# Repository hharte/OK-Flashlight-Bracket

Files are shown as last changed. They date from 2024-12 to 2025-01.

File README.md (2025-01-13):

# Speed-Wrap Flashlight Bracket

# Introduction

The OK Industries Speed-Wrap wire wrapping tool is useful for telecom and electronics work, where wire-wrapped connections are needed.

Over the years, the Speed-Wrap has been available in several models, most of which are still available today.

This project is a small 3D-printable bracket designed with [FreeCAD](https://freecad.org), that mounts to the rear of the tool, providing a stable mounting for a small flash light such as the [ThruNite Archer Mini](https://www.amazon.com/dp/B09XDTX7MX) or [Archer Pro v2](https://www.amazon.com/ThruNite-Flashlight-Archer-Pro-Rechargeable/dp/B0C2XSKKCT).

# Speed-Wrap Models

<table>
  <tr>
   <td>Model
   </td>
   <td>Bell System KS Number
   </td>
   <td>Description
   </td>
  </tr>
  <tr>
   <td>G-100
   </td>
   <td>KS-16363L1
   </td>
   <td>Aluminum housing
   </td>
  </tr>
  <tr>
   <td>G-100/R3278
   </td>
   <td>KS-16363L2
   </td>
   <td>Aluminum housing, newer style nose piece 
   </td>
  </tr>
  <tr>
   <td>G-200/R3278
   </td>
   <td>KS-16363L3
   </td>
   <td>Lexan housing, newer style nose piece 
   </td>
  </tr>
</table>

# Flashlights Supported

<table>
  <tr>
   <td>Brand
   </td>
   <td>Model
   </td>
   <td>Description
   </td>
  </tr>
  <tr>
   <td><a href="https://www.amazon.com/stores/ThruNite/page/18B3D79C-AD8C-49E3-A9F4-4489BCBD6C78">ThruNite</a>
   </td>
   <td><a href="https://www.amazon.com/dp/B09XDTX7MX">Archer Mini</a>
   </td>
   <td>14mm diameter body, USB-C charging.
   </td>
  </tr>
  <tr>
   <td><a href="https://www.amazon.com/stores/ThruNite/page/18B3D79C-AD8C-49E3-A9F4-4489BCBD6C78">ThruNite</a>
   </td>
   <td><a href="https://www.amazon.com/ThruNite-Flashlight-Archer-Pro-Rechargeable/dp/B0C2XSKKCT">Archer Pro v2</a>
   </td>
   <td>18mm diameter body, USB-C charging.
   </td>
  </tr>
</table>

# Installation

Use the included STL mesh files (14mm or 18mm) to print the bracket using a 3D printer.  I suggest using PETG filament for strength.  Use an M3x20 cap head bolt and M3 nut to attach the bracket to the rear of the Speed-Wrap.

Use two small zip ties to secure the flashlight to the top of the bracket.

# Photos

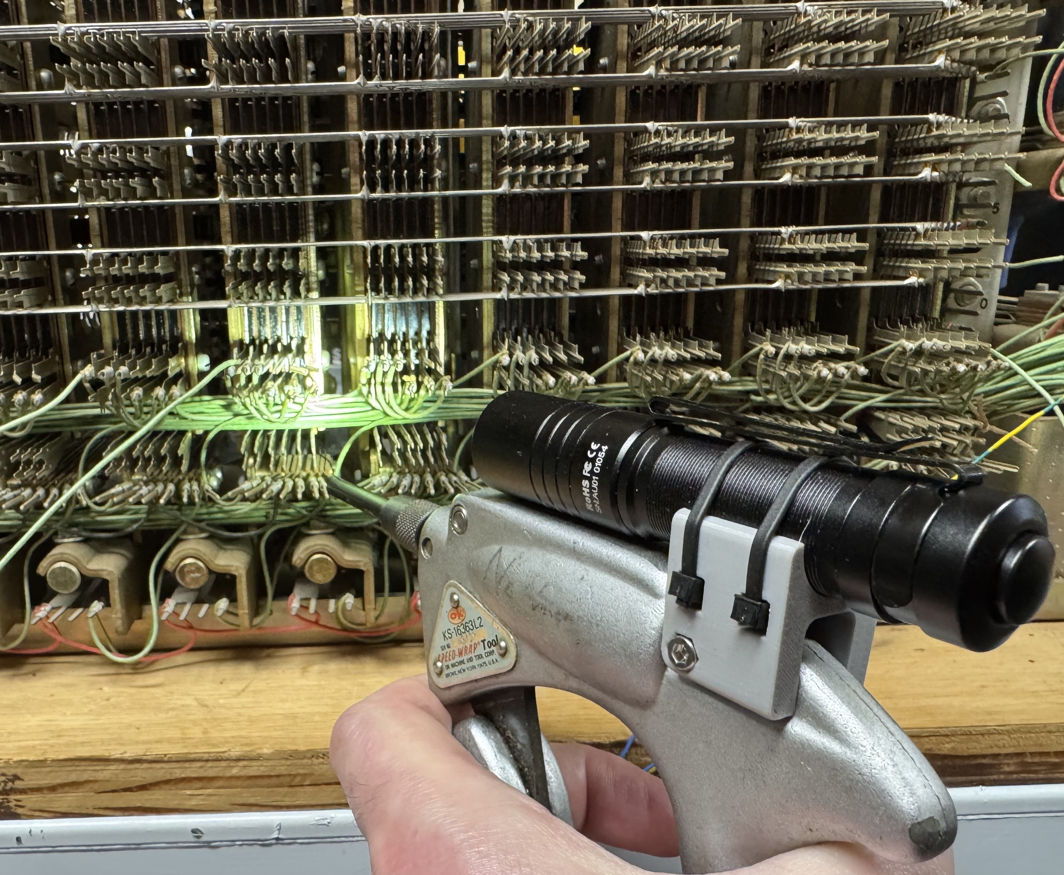
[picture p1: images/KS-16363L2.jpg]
Photo of the assembled bracket and Archer Pro v2 flashlight on a KS-16363L2 Speed-Wrap tool. image_tooltip


## Assembled bracket and Archer Pro v2 flashlight on a KS-16363L2 Speed-Wrap tool.

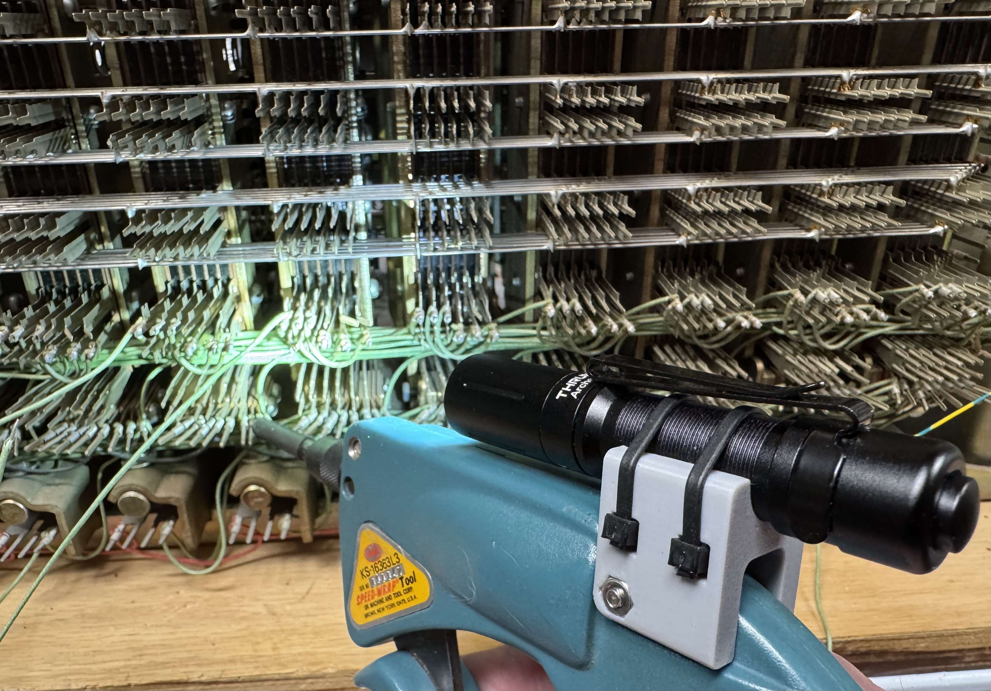
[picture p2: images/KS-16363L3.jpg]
Photo of the assembled bracket and Archer Mini flashlight on a KS-16363L3 Speed-Wrap tool. image_tooltip


## Assembled bracket and Archer Mini flashlight on a KS-16363L3 Speed-Wrap tool.

# Cleaning, Lubricating, Rebuilding

Remove all old grease from the gears, and if the bearings don’t spin freely, you may need to remove the old grease from those as well, and re-pack.  You can 3D-print the `BearingGreaseFitting.stl` to help re-pack the bearings, or you can simply replace the bearings.

The bearings are ⅜” OD, ⅛” ID, 5/32” Width.  These are some of the available bearing replacements on Amazon:

[https://www.amazon.com/HiPicco-R2-2RS-Bearings-Bearing-Pre-Lubricated/dp/B0C74WTY1K](https://www.amazon.com/HiPicco-R2-2RS-Bearings-Bearing-Pre-Lubricated/dp/B0C74WTY1K)

[https://www.amazon.com/uxcell-R2-2RS-Groove-Bearing-Bearings/dp/B0824WN2RB](https://www.amazon.com/uxcell-R2-2RS-Groove-Bearing-Bearings/dp/B0824WN2RB)

[https://www.amazon.com/uxcell-8-inchx3-8-inchx5-Shielded-Bearings/dp/B0824VSF74](https://www.amazon.com/uxcell-8-inchx3-8-inchx5-Shielded-Bearings/dp/B0824VSF74)

***<span style="text-decoration:underline;">Note:</span>***

When cleaning and lubricating the gears and bearings, it is very important to get the ring gear aligned properly.  Don’t press the bearing all the way into the recess in the case.  Instead, press the bearing in slightly, just enough to hold the ring gear in place while you assemble the tool.  While tightening the case, the bearing will be pushed into the recess just enough to maintain proper contact with the pinion gear.  If the tool is noisy, or doesn’t return quickly when the handle is released, the gear alignment is most likely incorrect.  Take it apart again, and assemble as described above.

## Lubrication of gears

Use a small amount of a light grease such as [Permatex White Lithium Grease](https://www.amazon.com/dp/B000HBNV58).

# References

[Manual Wire Wrapping Tools User’s Guide](https://jonard.com/sites/default/files/product_files/Manual%20Wire%20Wrapping%20Tools%20Users%20Guide%20%284%29.pdf)

[Jonard Wire Wrap Tool Page](https://jonard.com/manual-wire-wrap-and-unwrap-guns-0)

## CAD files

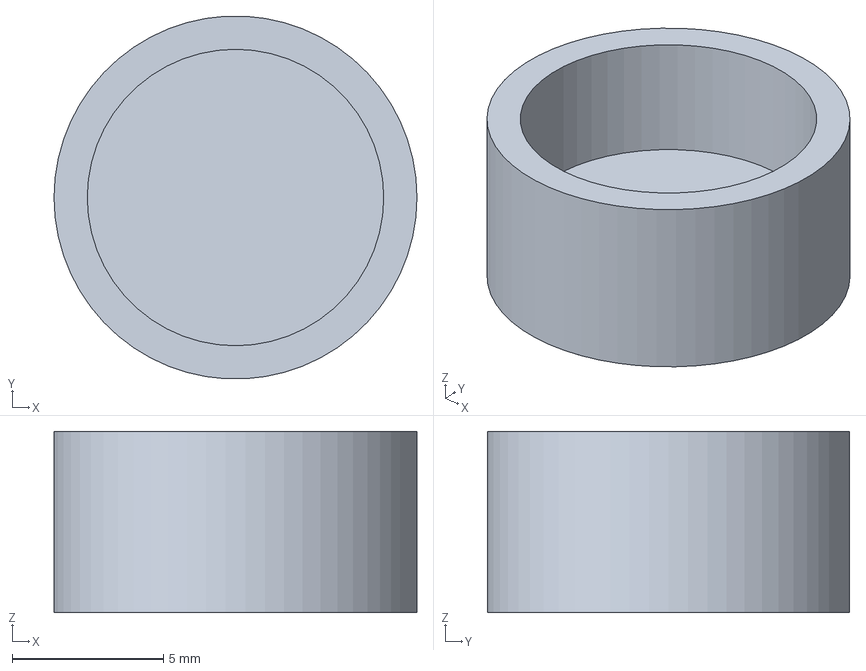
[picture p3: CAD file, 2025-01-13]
BearingGreaseFitting.FCStd
12.0 x 12.0 x 6.00 mm

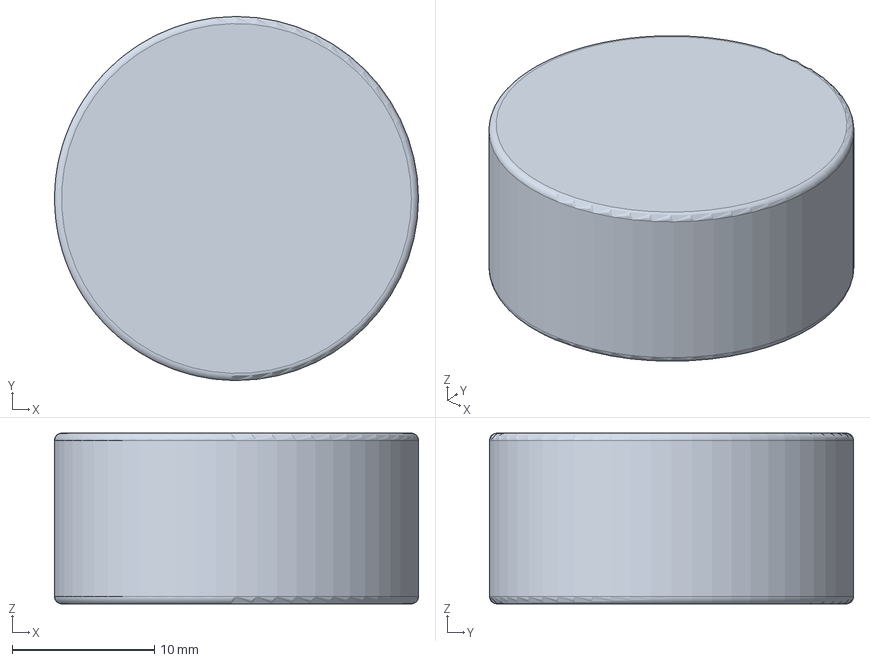
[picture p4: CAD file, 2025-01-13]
BatteryCap.FCStd
25.6 x 25.6 x 12.0 mm

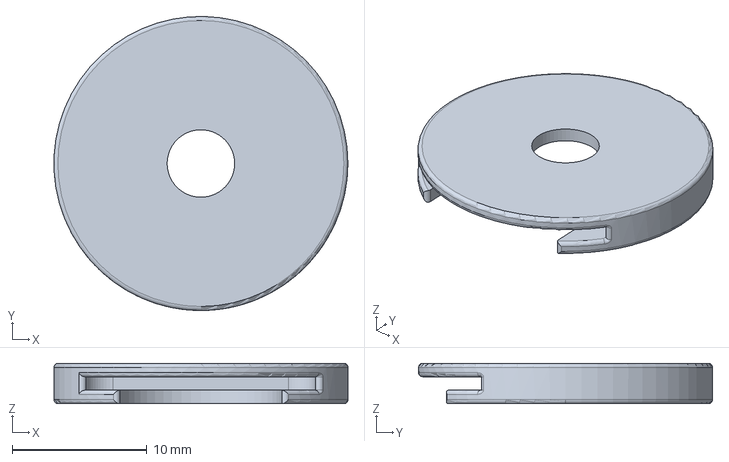
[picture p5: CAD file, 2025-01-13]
BatterySpringBase.FCStd
21.8 x 21.8 x 3.00 mm

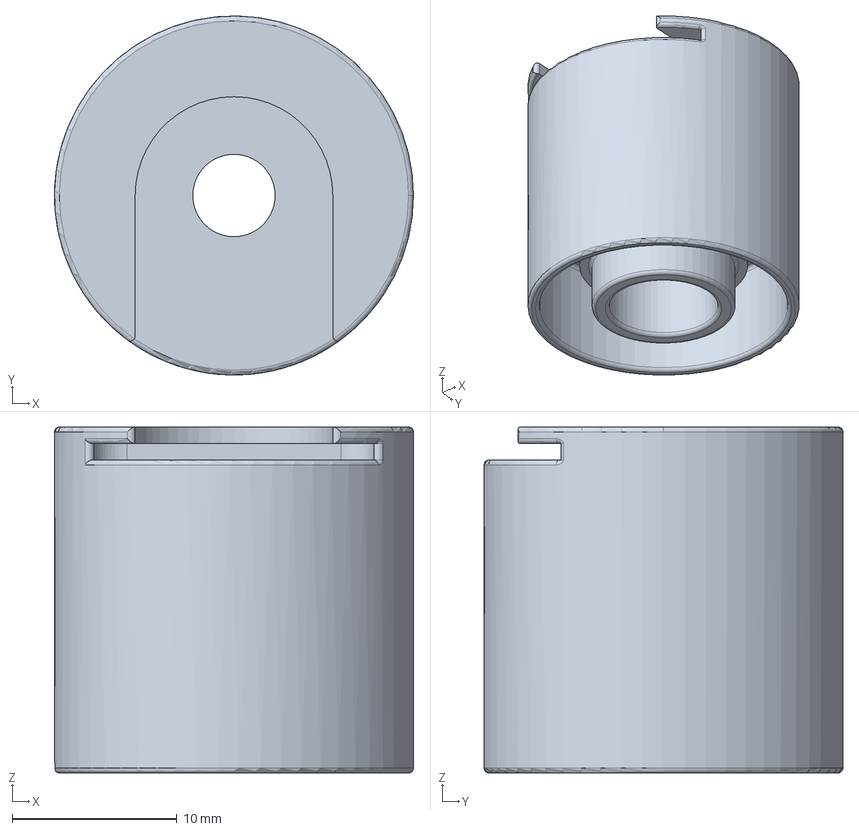
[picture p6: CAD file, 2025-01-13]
BatteryAdapter.FCStd
21.8 x 21.8 x 21.0 mm

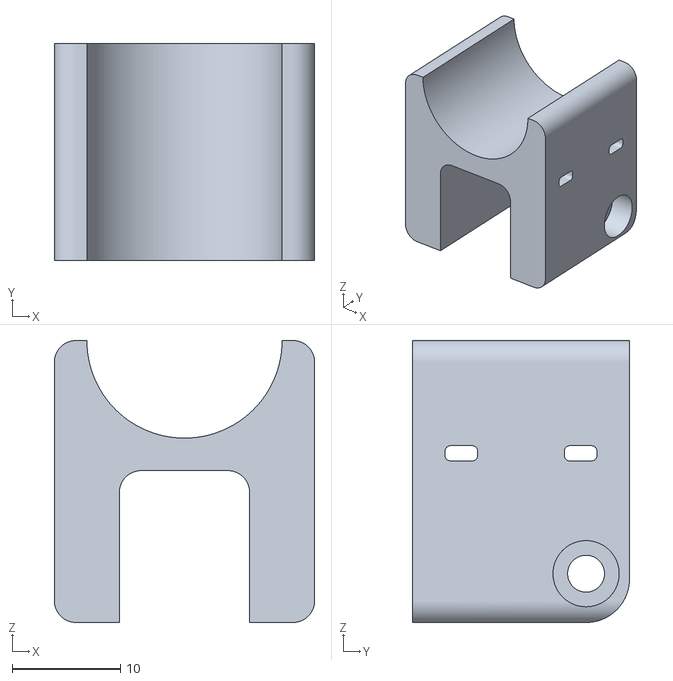
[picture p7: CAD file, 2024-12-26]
OK-Flashlight-Bracket_D18mm.stl
24.0 x 20.0 x 26.0

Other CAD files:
OK-Flashlight-Bracket_D14mm.stl
OK-Flashlight-Bracket.FCStd
BearingGreaseFitting.stl

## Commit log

2024-12-25 Initial version.
    [OK-Flashlight-Bracket.FCStd, OK-Flashlight-Bracket.stl]
2024-12-26 Adjust the model to support flashlights up to 19mm in diameter.
    * Two are provided as an STL mesh: 14mm and 18mm flashlight body diameter.
    [OK-Flashlight-Bracket.FCStd, OK-Flashlight-Bracket.stl, OK-Flashlight-Bracket_D14mm.stl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]
2024-12-28 Add photos of the installed bracket.
2025-01-13 Update README with lubrication and reassembly notes.
    * Also add a battery adapter to allow replacement of the NiMH cells
    from the PTX-B battery (for the battery-operated wire wrap tool)
    with a 21700 Lithium battery. Note that the lithium battery
    cannot be charged with the stock charger. I selected a 21700
    battery that had an integral USB-C charging port, so the charger
    is not needed at all.
    [BatteryAdapter.FCStd, BatteryCap.FCStd, BatterySpringBase.FCStd]
2025-01-13 Add notes on bearing repacking and add 3D-printable tool to help.
    [BearingGreaseFitting.FCStd, BearingGreaseFitting.stl]
